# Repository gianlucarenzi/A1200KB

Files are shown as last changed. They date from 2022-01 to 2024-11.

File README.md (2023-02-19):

# A1200KB Amiga 1200 mechanical keyboard

As of right now this is revision 4. I know it could be improved very, very slightly by changing the position of key groups by less than a millimetre but I think it's complete now. 

This PCB design was reverse-engineered from the original keyboard in an Amiga 1200. It is designed to connect to your Amiga 1200 with no modifications to the original machine, just take out the original keyboard and store it away safely. If you want an A600 keyboard, see my other repositories.

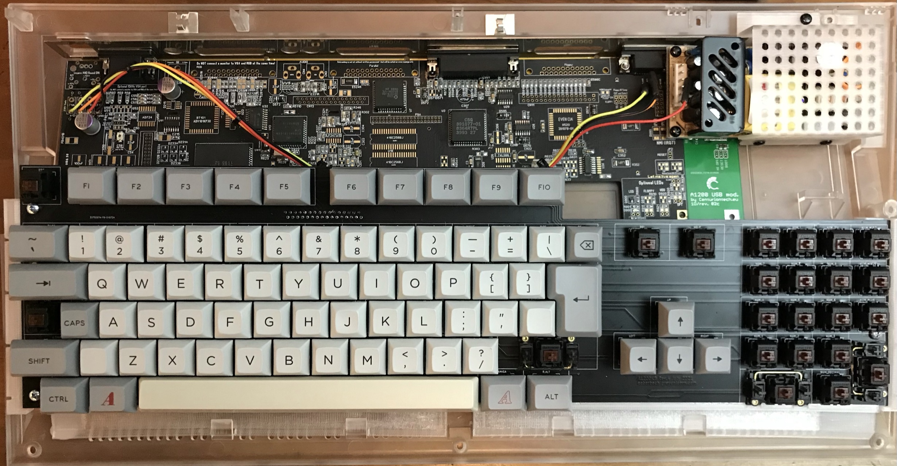
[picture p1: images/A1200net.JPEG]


The A1200.net case (with internal PSU and partially-completed [ReAmiga](http://www.reamiga.info/) board)

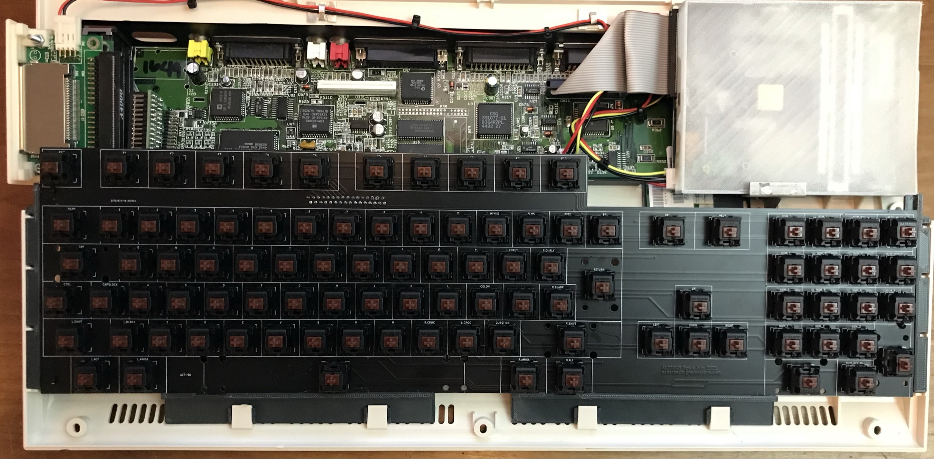
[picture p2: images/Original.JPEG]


The original Amiga case (with CF disk system and transparent floppy cover)

## Requirements
To make a working keyboard for your Amiga 1200, you need:

- one PCB (this project)
- MX-compatible PCB-mount keyswitches, one for each key
- one LED (caps lock)
- one FFC connector, 32-way RA 1.25mm pitch. Molex 52044-3245 is one example, available from Mouser Electronics.
- one FFC ribbon cable, 32-way, 1.25mm pitch. Molex 15168-0400 is one example, available from Mouser Electronics.
- keycaps
- some way to mount the keyboard inside the Amiga (3D print some brackets from the STL folder...)
 
## Design
The Amiga 1200 keyboard is a simple passive key matrix connected via a 31-conductor cable. Some special keys are not on the matrix but have a dedicated circuit, such as the CTRL and Amiga keys - this is why so many conductors are necessary. The original Amiga 1200 PCB uses a 31-way FFC connector, I was not able to buy this anywhere as they are long discontinued. However cutting one conductor away from the cable allows it to fit in the Amiga connector with 31 conductors and to the keyboard with 32 conductors and everything is fine. The specified FFC cable is slightly longer than required but in 2019 there is not  a lot of choice available, so the longer one will do. 
I had my boards made with 1.6mm PCB substrate as any other thickness gets disproportionally expensive, no other special options. Using a piece of aluminium rail, 10x3mm, will make it as stiff as a keyboard should be while maintaining enough space underneath for an accelerator or Indivision etc. This is supported either side by the 3D printed mounts. Cover the aluminium with some kapton or other insulation if you have other internal components that may come dangerously close but in a stock Amiga there is plenty of clearance.

### Amiga Keycaps
These aren't widely available. I've tried making some using a blank set of keycaps from aliexpress and a laser etcher, but I do not know of anywhere that sells a MX-stem set of Amiga keycaps. I am using a 9U space bar but you can just as easily use 7U. If gaps either side of the space bother you, 3D print something to fill the space.

If you want a perfect set of keys, visit pimpmykeyboard.com - it will not be cheap but if you look hard enough you will find every key, even the Amiga keys, and you can have any legend printed on any size keycap so it is possible to make a perfect set. It will not be cheap. You can se a partial sample in the A1200.net picture. I am currently waiting for the extra numpad keys to arrive to complete this keyboard.

## Construction
Without going into all the detail here - as there is lots of detail on www.grayunicorn.com - I rate this a mid-level project. There is no power, no delicate soldering, and nothing can really be inserted the wrong way. Mounting the keyboard requires 3D printing the files you will find in the 3Dfiles folder.

If you have a replacement case produced by A1200.net then pick that folder, else the other folder. I don't know about cases made by ESCOM but I don't think they are at all different from the Commodore cases. I printed these in PETG, 0.4mm nozzle, 0.2mm layer height, supports are necessary. Mounting the keyboard with these designs allows the use of an accelerator card with a thick SIMM; I may design alternates if I get a slimmer accelerator, bringing the keys further back into the case but there is not much room.
 
You can damage your Amiga if you don't know what you are doing. Please be careful and if you are not experienced in projects like this get some help, maybe vist your local makerspace, and don't hurt yourself or your computer.

## Share
Most of all - if you have any suggestions for improvements, adding an issue or a pull request to this repo would be much appreciated. And share your project with the Amiga community, I'd really like to see what you made.

#### Donate?
I hate to think what this has cost so far. It's been fun and I'd do it again, but if you'd like to help the next project happen that would be awesome.



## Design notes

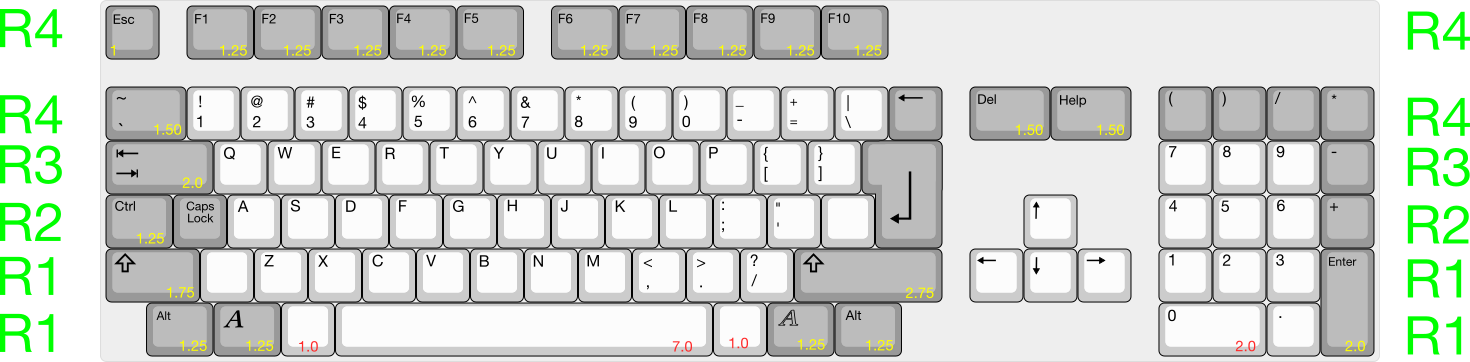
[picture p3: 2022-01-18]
PlatePCB/amiga-keyboard-a500-a1200.png

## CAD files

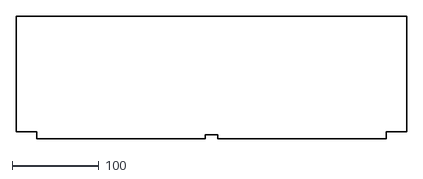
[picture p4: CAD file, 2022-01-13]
created/keyboard_full-Edge_Cuts.dxf
449.3 x 141.4

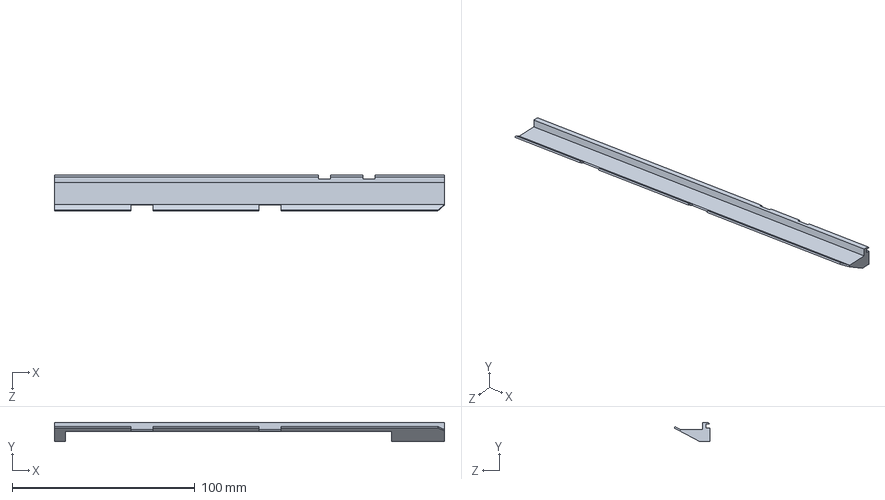
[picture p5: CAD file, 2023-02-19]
3Dfiles/A1200.net case/rev4/Right base.SLDPRT
213.5 x 10.6 x 19.5 mm

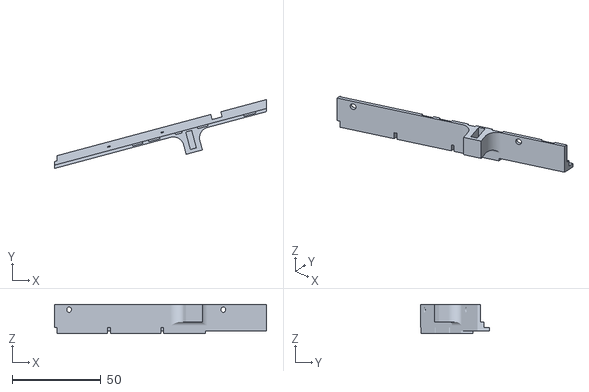
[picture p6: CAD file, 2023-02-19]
3Dfiles/Original Amiga case/rev2+3/Keyboard support left r2.stl
119.5 x 38.9 x 16.5

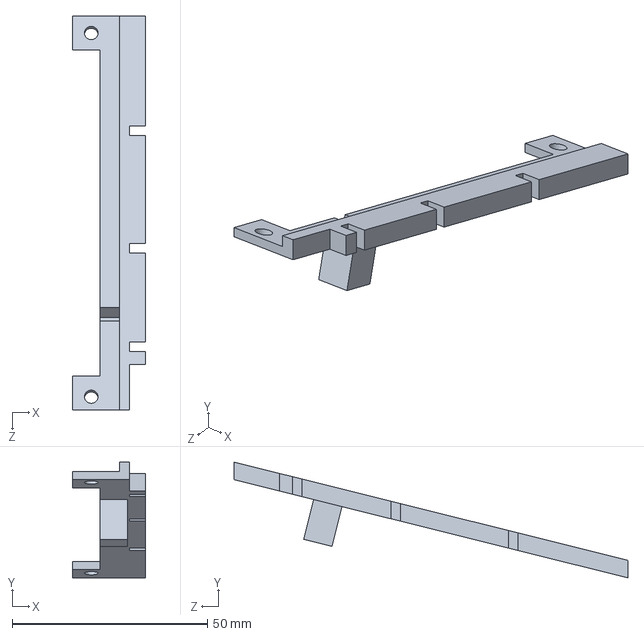
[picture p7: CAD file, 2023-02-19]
3Dfiles/Original Amiga case/rev4/Left side.SLDPRT
18.6 x 29.7 x 100.9 mm

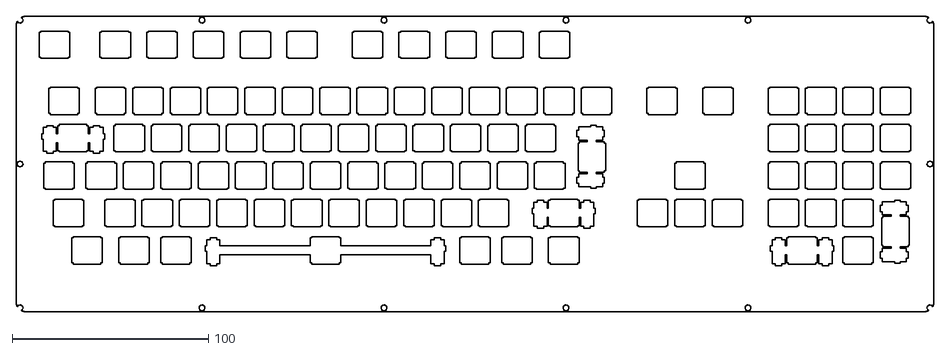
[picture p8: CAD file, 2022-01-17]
PlatePCB/Amiga_Keyboard_Plate_Builder_A1200-A500.dxf
467.7 x 150.6

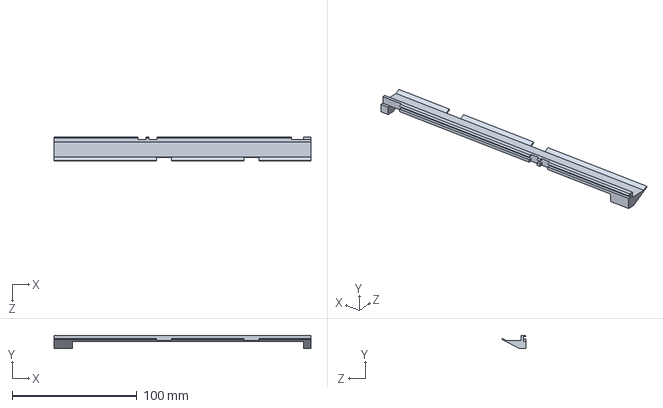
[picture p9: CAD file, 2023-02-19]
3Dfiles/A1200.net case/rev4/Left base.SLDPRT
206.0 x 10.6 x 19.5 mm

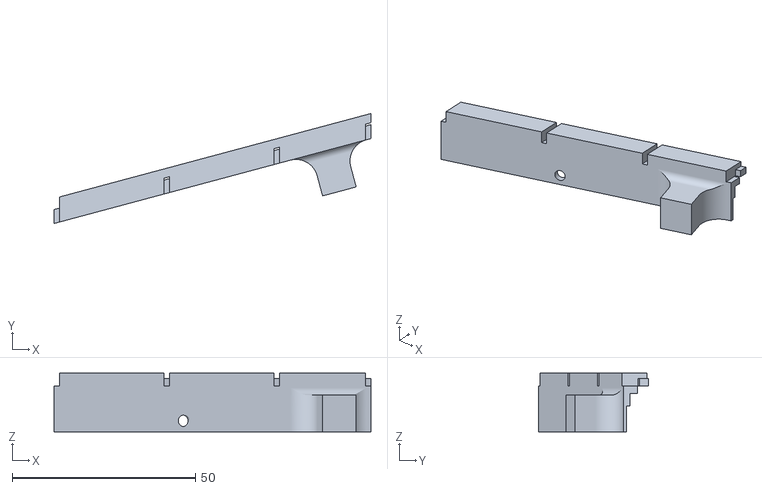
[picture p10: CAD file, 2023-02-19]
3Dfiles/Original Amiga case/rev2+3/Keyboard support right r2.stl
86.5 x 30.0 x 16.0

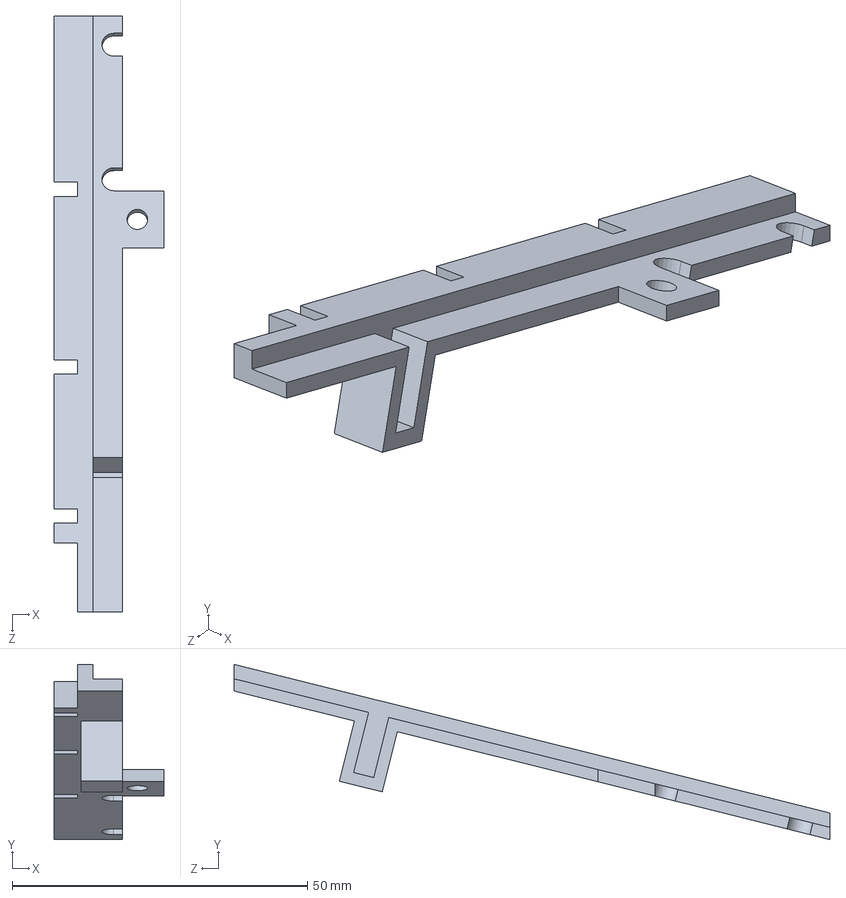
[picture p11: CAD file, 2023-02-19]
3Dfiles/Original Amiga case/rev4/Right side.SLDPRT
18.6 x 29.7 x 100.9 mm

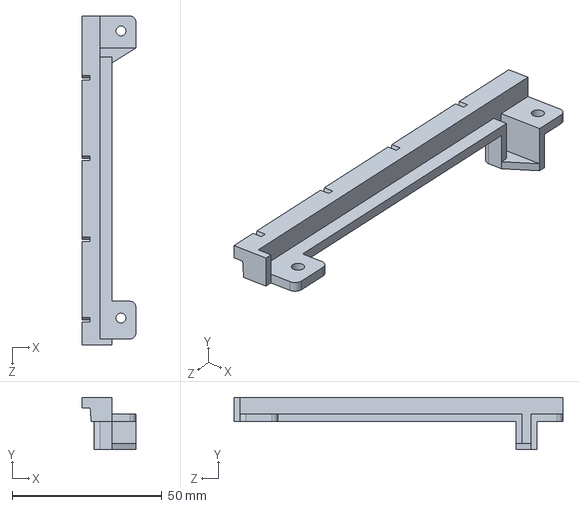
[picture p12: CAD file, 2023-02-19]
3Dfiles/A1200.net case/rev4/Left side.SLDPRT
18.0 x 17.5 x 110.0 mm

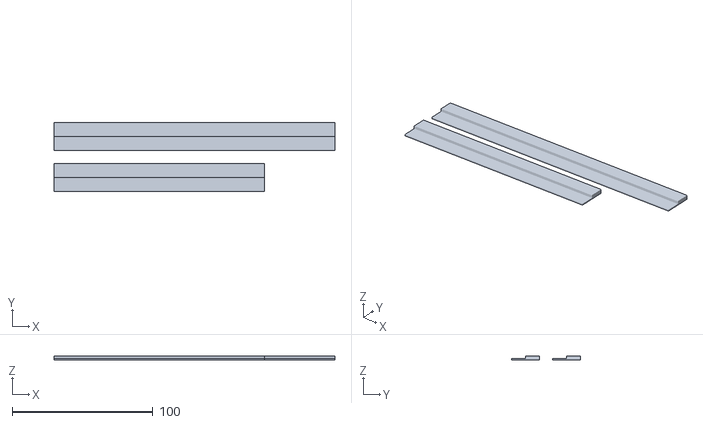
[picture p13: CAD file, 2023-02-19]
3Dfiles/Original Amiga case/rev2+3/kb base.stl
200.0 x 49.0 x 3.00

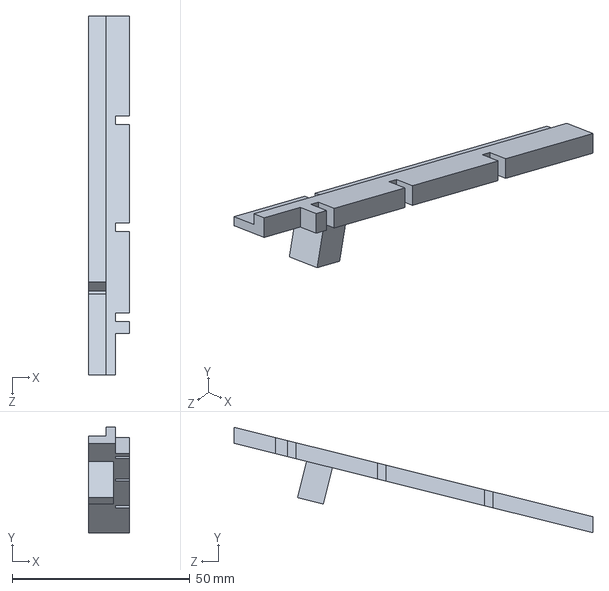
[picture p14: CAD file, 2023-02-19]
3Dfiles/Original Amiga case/rev4/Left side (for mirror).SLDPRT
11.6 x 29.7 x 100.9 mm

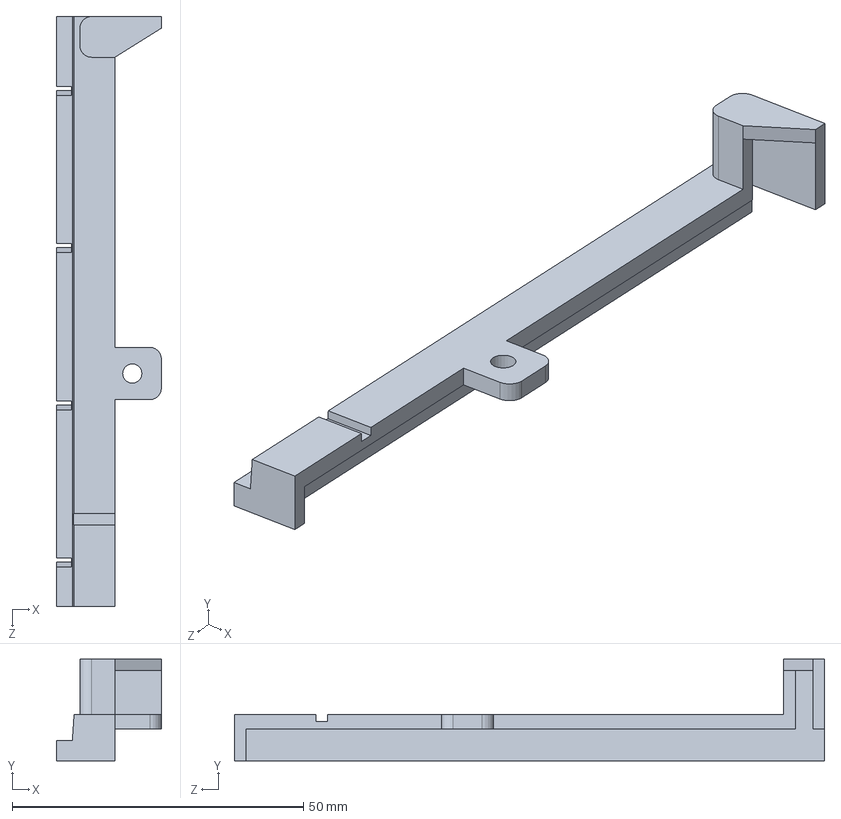
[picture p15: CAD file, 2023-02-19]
3Dfiles/A1200.net case/rev4/Right side.SLDPRT
18.0 x 17.5 x 101.3 mm

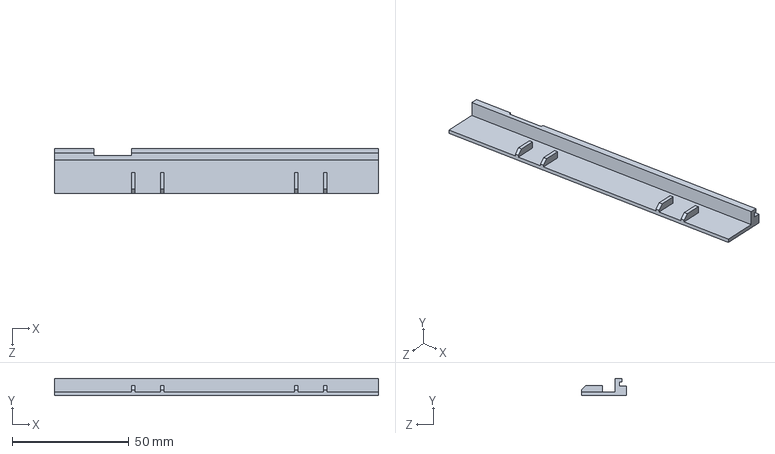
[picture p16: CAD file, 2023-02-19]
3Dfiles/Original Amiga case/rev4/Base.SLDPRT
139.0 x 7.35 x 19.5 mm

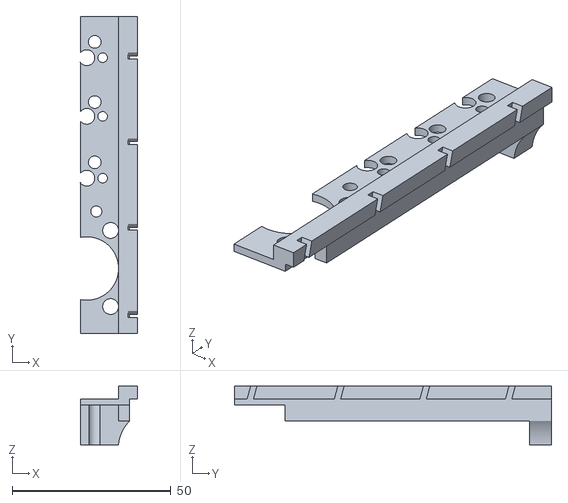
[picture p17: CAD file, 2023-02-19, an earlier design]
3Dfiles/A1200.net case/rev3/Right side.stl
18.0 x 100.0 x 18.5

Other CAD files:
PlatePCB/spacebar-9U-1U-7U-1U.dxf
3Dfiles/A1200.net case/rev3/Right base support.stl
3Dfiles/A1200.net case/rev3/Brace insulator and spacer.stl
3Dfiles/A1200.net case/rev3/Left base support.stl
3Dfiles/A1200.net case/rev3/Left side.stl
3Dfiles/A1200.net case/rev4/Left base.STL
3Dfiles/A1200.net case/rev4/Left side.STL
3Dfiles/A1200.net case/rev4/Right base.STL
3Dfiles/A1200.net case/rev4/Right side.STL
3Dfiles/Original Amiga case/rev4/Base.STL
3Dfiles/Original Amiga case/rev4/Left side.STL
3Dfiles/Original Amiga case/rev4/Right side.STL
created/keyboard_full-B_Mask.dxf
created/keyboard_full-F_Silkscreen.dxf

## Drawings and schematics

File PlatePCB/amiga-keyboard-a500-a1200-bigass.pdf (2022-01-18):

R4

R4

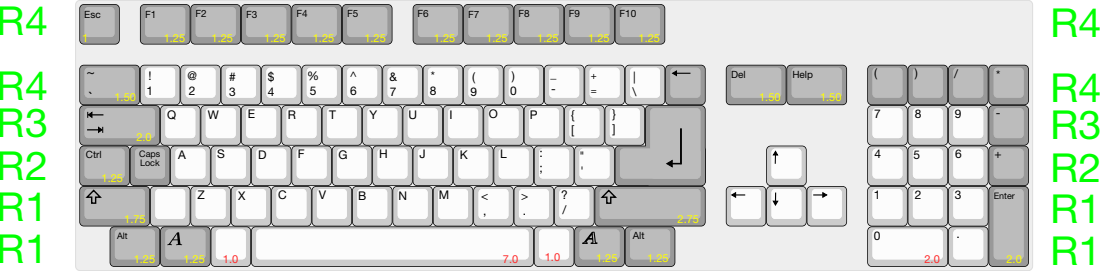
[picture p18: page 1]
Esc; Del; Help `; Caps Lock; Ctrl; Alt; Enter

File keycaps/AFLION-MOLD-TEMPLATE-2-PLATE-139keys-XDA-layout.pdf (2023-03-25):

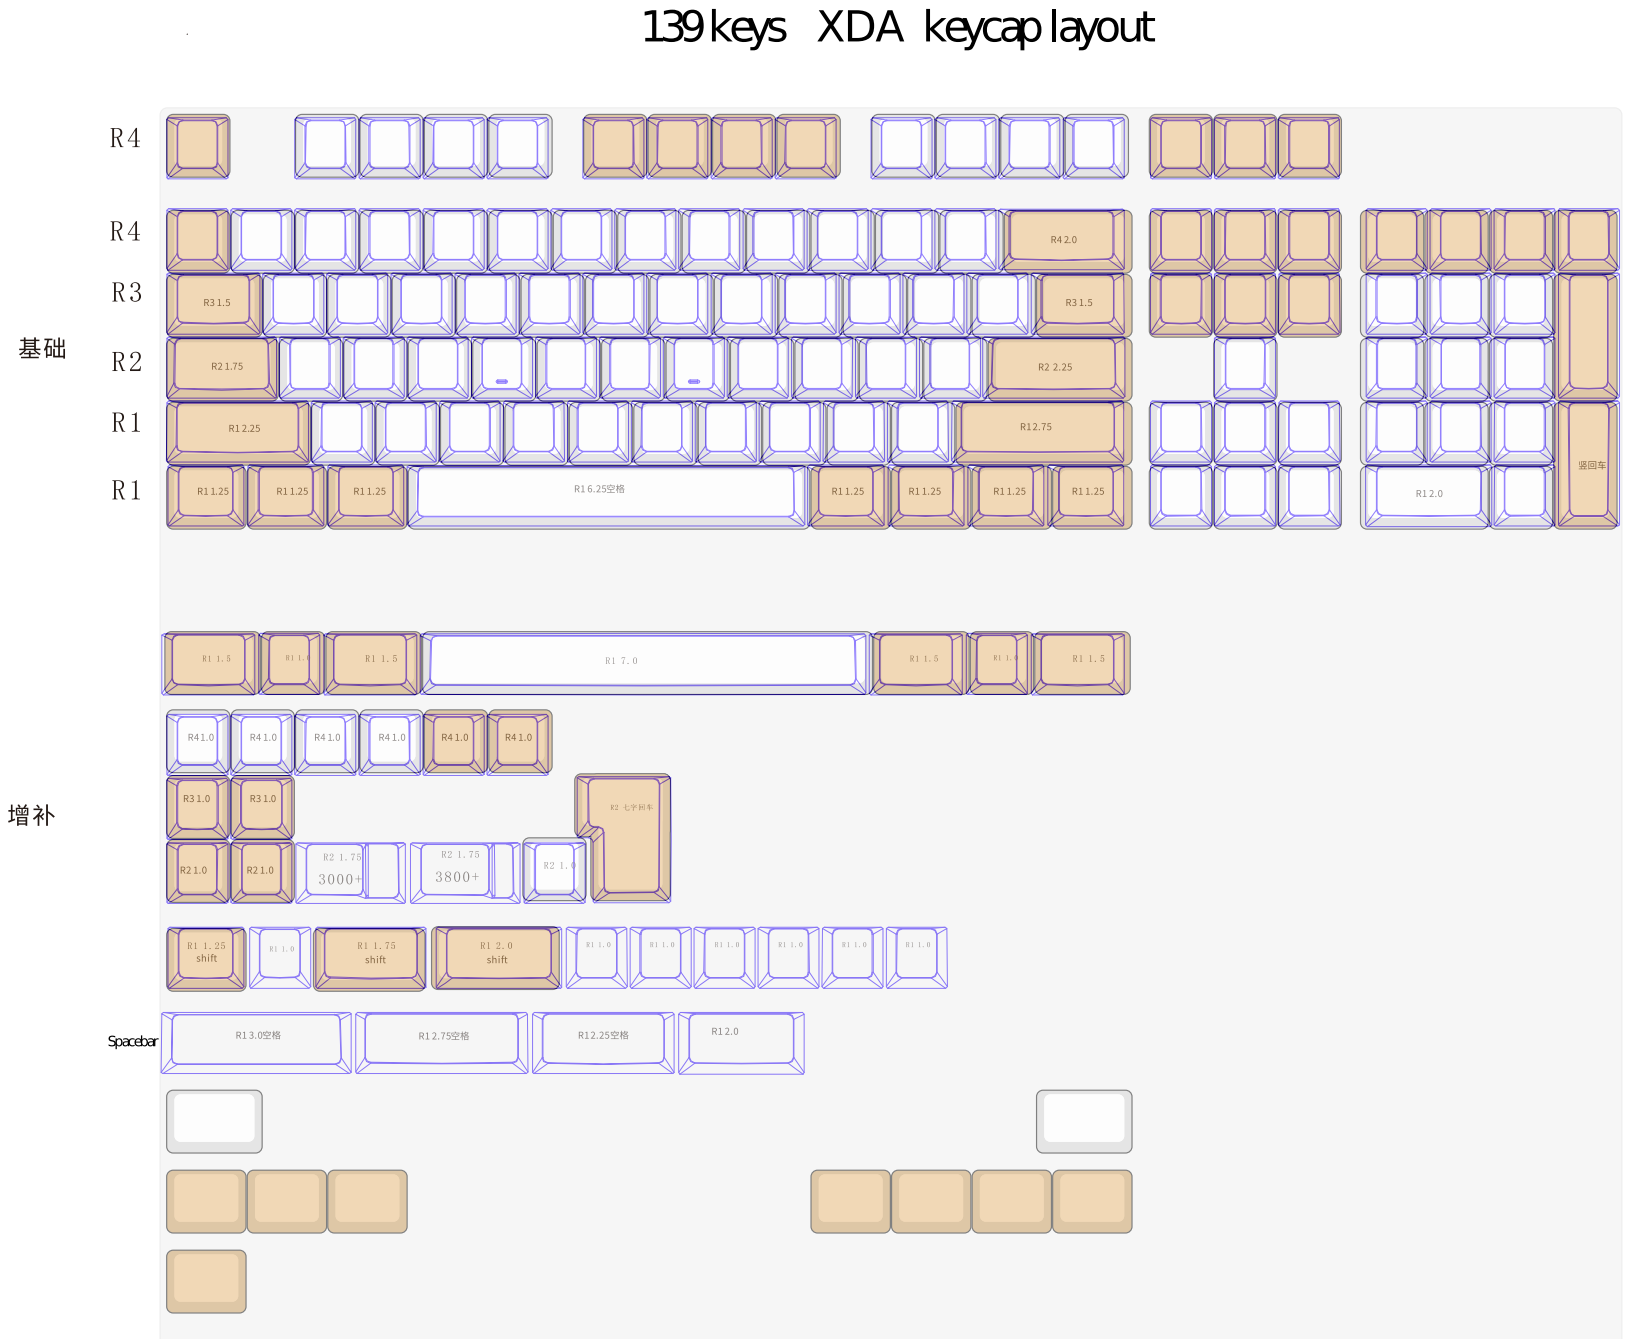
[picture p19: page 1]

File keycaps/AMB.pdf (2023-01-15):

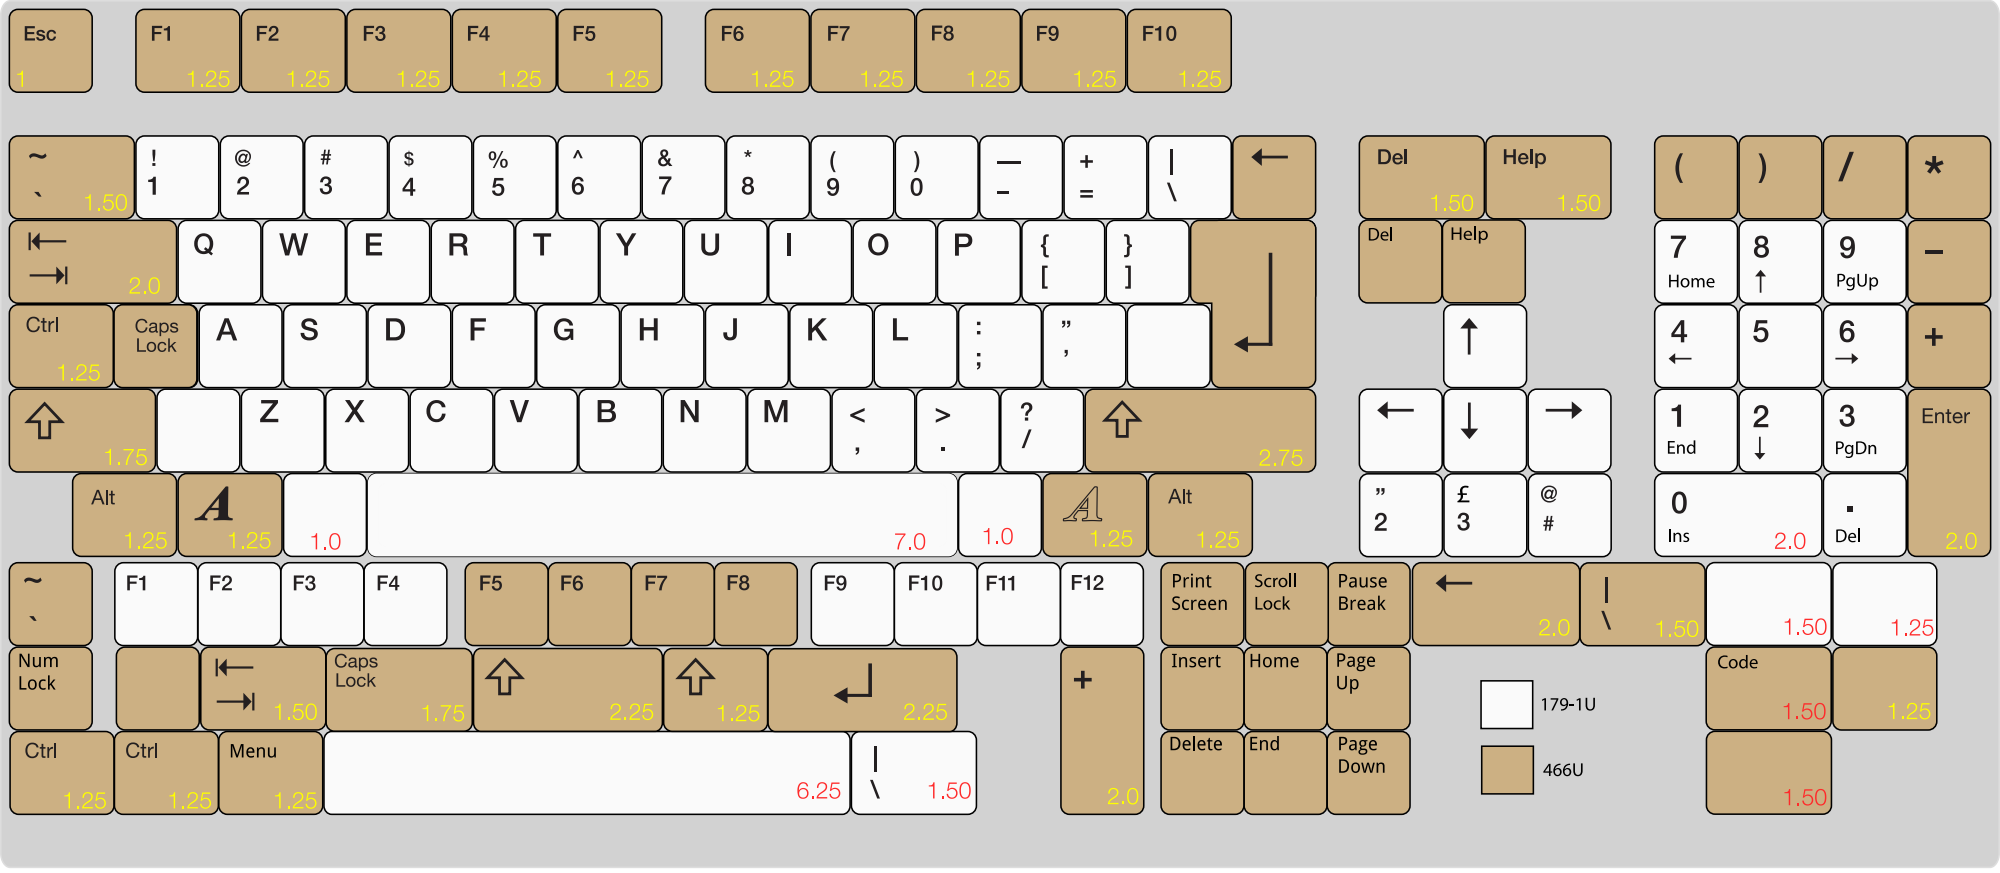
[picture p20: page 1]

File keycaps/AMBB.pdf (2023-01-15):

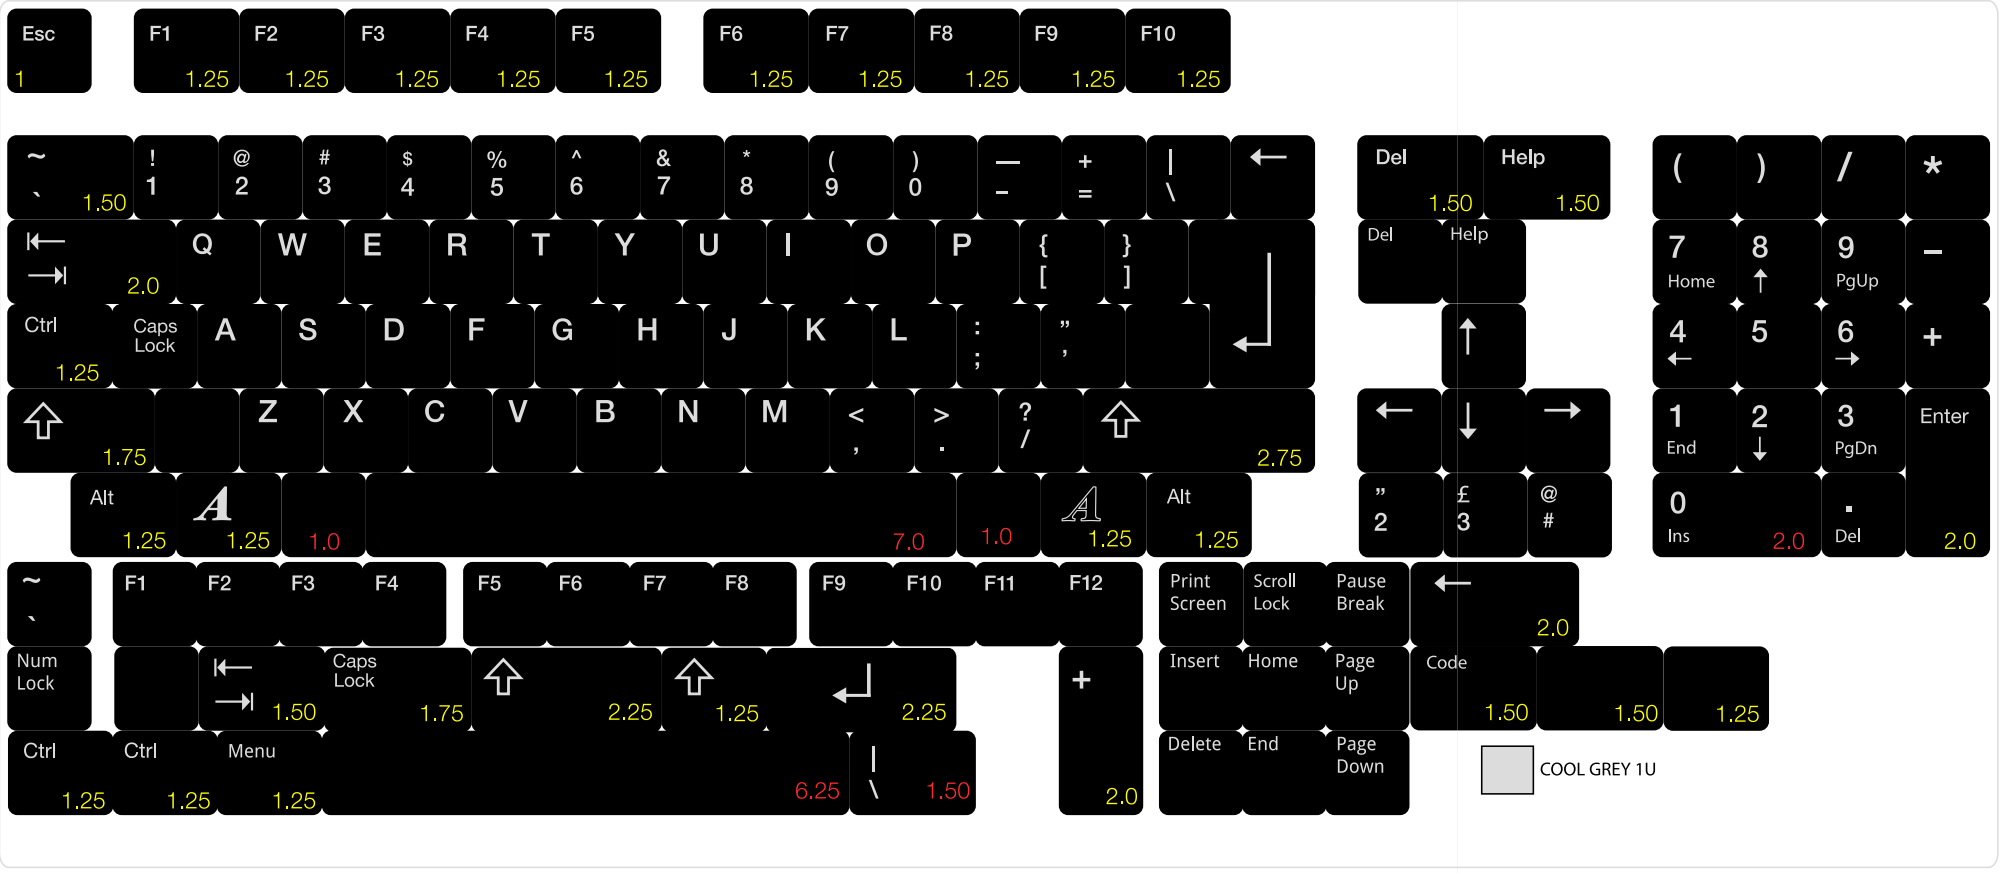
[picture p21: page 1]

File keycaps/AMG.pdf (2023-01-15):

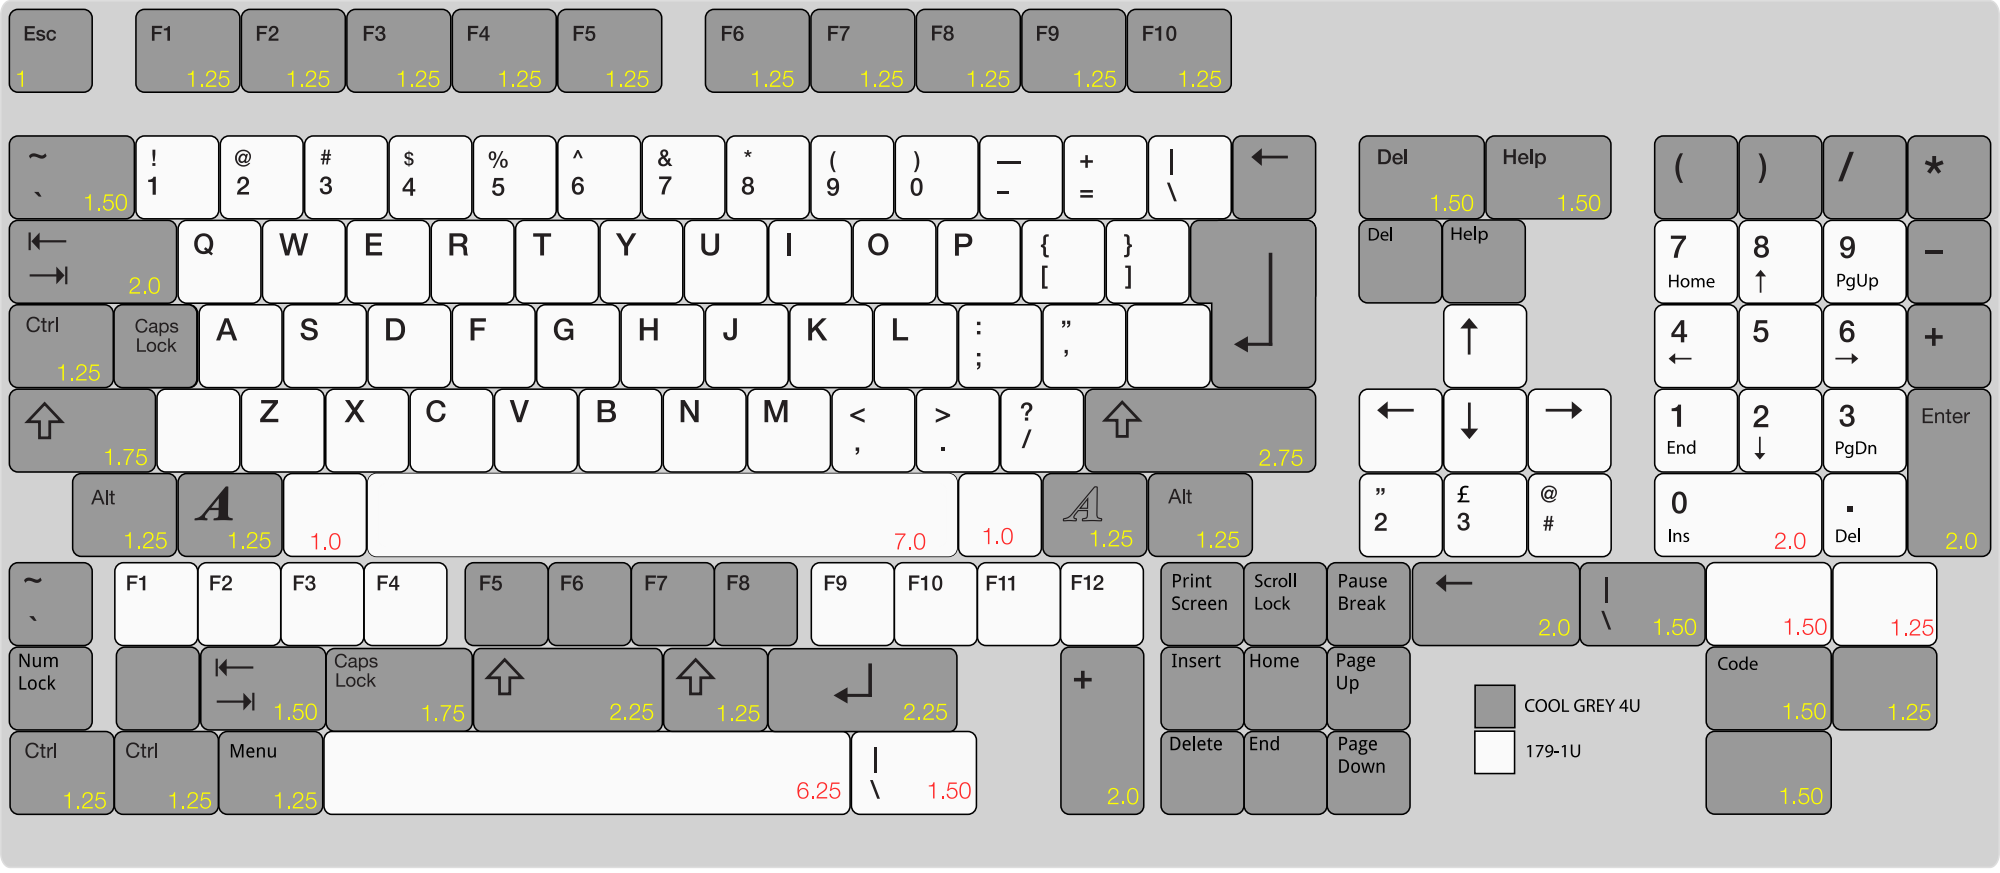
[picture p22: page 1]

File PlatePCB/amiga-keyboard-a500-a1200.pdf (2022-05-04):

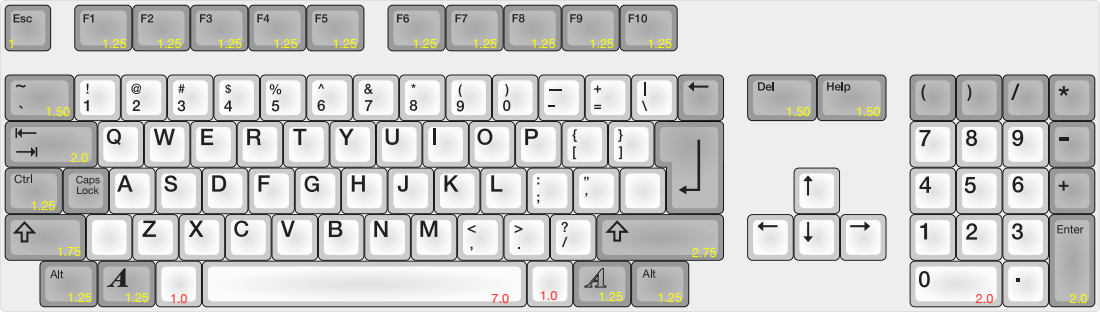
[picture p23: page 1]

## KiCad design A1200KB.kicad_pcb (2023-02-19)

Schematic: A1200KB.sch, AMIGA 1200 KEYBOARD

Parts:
J1: Conn_01x32_Female; FFC-1.25mm-RA-5204403245
K1: ESC; MXOnly-1U-NoLED
K2: F1; MXOnly-1.25U-NoLED
K3: F2; MXOnly-1.25U-NoLED
K4: F3; MXOnly-1.25U-NoLED
K5: F4; MXOnly-1.25U-NoLED
K6: F5; MXOnly-1.25U-NoLED
K7: F6; MXOnly-1.25U-NoLED
K8: F7; MXOnly-1.25U-NoLED
K9: F8; MXOnly-1.25U-NoLED
K10: F9; MXOnly-1.25U-NoLED
K11: F10; MXOnly-1.25U-NoLED
K12: TILDE; MXOnly-1.5U-NoLED
K13: 1; MXOnly-1U-NoLED
K14: 2; MXOnly-1U-NoLED
K15: 3; MXOnly-1U-NoLED
K16: 4; MXOnly-1U-NoLED
K17: 5; MXOnly-1U-NoLED
K18: 6; MXOnly-1U-NoLED
K19: 7; MXOnly-1U-NoLED
K20: 8; MXOnly-1U-NoLED
K21: 9; MXOnly-1U-NoLED
K22: 0; MXOnly-1U-NoLED
K23: MINUS; MXOnly-1U-NoLED
K24: PLUS; MXOnly-1U-NoLED
K25: PIPE; MXOnly-1U-NoLED
K26: BS; MXOnly-1U-NoLED
K27: DEL; MXOnly-1.5U-NoLED
K28: HELP; MXOnly-1.5U-NoLED
K29: NUM_(; MXOnly-1U-NoLED
K30: NUM_); MXOnly-1U-NoLED
K31: NUM_DIV; MXOnly-1U-NoLED
K32: NUM_MULT; MXOnly-1U-NoLED
K33: TAB; MXOnly-2U-NoLED
K34: Q; MXOnly-1U-NoLED
K35: W; MXOnly-1U-NoLED
K36: E; MXOnly-1U-NoLED
K37: R; MXOnly-1U-NoLED
K38: T; MXOnly-1U-NoLED
K39: Y; MXOnly-1U-NoLED
K40: U; MXOnly-1U-NoLED
K41: I; MXOnly-1U-NoLED
K42: O; MXOnly-1U-NoLED
K43: P; MXOnly-1U-NoLED
K44: L.CURLY; MXOnly-1U-NoLED
K45: R.CURLY; MXOnly-1U-NoLED
K46: RETURN; MXOnly-ISO
K47: NUM_7; MXOnly-1U-NoLED
K48: NUM_8; MXOnly-1U-NoLED
K49: NUM_9; MXOnly-1U-NoLED
K50: NUM_MINUS; MXOnly-1U-NoLED
K51: CTRL; MXOnly-1.25U-NoLED
K52: CAPSLOCK; MXOnly-1U
K53: A; MXOnly-1U-NoLED
K54: S; MXOnly-1U-NoLED
K55: D; MXOnly-1U-NoLED
K56: F; MXOnly-1U-NoLED
K57: G; MXOnly-1U-NoLED
K58: H; MXOnly-1U-NoLED
K59: J; MXOnly-1U-NoLED
K60: K; MXOnly-1U-NoLED
K61: L; MXOnly-1U-NoLED
K62: COLON; MXOnly-1U-NoLED
K63: \"; MXOnly-1U-NoLED
K64: R.BLANK; MXOnly-1U-NoLED
K65: UP; MXOnly-1U-NoLED
K66: NUM_4; MXOnly-1U-NoLED
K67: NUM_5; MXOnly-1U-NoLED
K68: NUM_6; MXOnly-1U-NoLED
K69: NUM_PLUS; MXOnly-1U-NoLED
K70: L.SHIFT; MXOnly-1.75U-NoLED
K71: L.BLANK; MXOnly-1U-NoLED
K72: Z; MXOnly-1U-NoLED
K73: X; MXOnly-1U-NoLED
K74: C; MXOnly-1U-NoLED
K75: V; MXOnly-1U-NoLED
K76: B; MXOnly-1U-NoLED
K77: N; MXOnly-1U-NoLED
K78: M; MXOnly-1U-NoLED
K79: R.CROC; MXOnly-1U-NoLED
K80: L.CROC; MXOnly-1U-NoLED
K81: QUESTION; MXOnly-1U-NoLED
K82: R.SHIFT; MXOnly-2.75U-NoLED
K83: LEFT; MXOnly-1U-NoLED
K84: DOWN; MXOnly-1U-NoLED
K85: RIGHT; MXOnly-1U-NoLED
K86: NUM_1; MXOnly-1U-NoLED
K87: NUM_2; MXOnly-1U-NoLED
K88: NUM_3; MXOnly-1U-NoLED
K89: NUM_ENTER; MXOnly-2U-NoLED
K90: L.ALT; MXOnly-1.25U-NoLED
K91: L.AMIGA; MXOnly-1.25U-NoLED
K92: SPACE; MXOnly-7U-NoLED
K93: R.AMIGA; MXOnly-1.25U-NoLED
K94: R.ALT; MXOnly-1.25U-NoLED
K95: NUM_0; MXOnly-2U-NoLED
K96: NUM_DECIMAL; MXOnly-1U-NoLED

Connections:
/1: J1.1, K33.1, K34.2, K35.2, K36.2, K37.2, K38.2, K39.1, K40.2, K41.2, K42.2, K43.2, K44.2, K45.2, K46.1, K83.2
/2: J1.2, K27.2, K52.2, K53.2, K54.2, K55.2, K56.2, K57.2, K58.1, K59.2, K60.2, K61.2, K62.2, K63.2, K64.2, K85.2
/3: J1.3, K26.2, K71.2, K72.2, K73.2, K74.2, K75.2, K76.2, K77.1, K78.2, K79.2, K80.2, K81.2, K84.1, K92.2
/4: J1.4, K32.2, K47.2, K48.2, K49.2, K50.2, K66.2, K67.2, K68.2, K69.2, K86.2, K87.2, K88.2, K89.2, K95.1, K96.2
/5: J1.5, K12.2, K13.2, K14.2, K15.2, K16.2, K17.2, K18.1, K19.2, K20.1, K21.2, K22.2, K23.2, K24.2, K25.1, K65.1
/6: J1.6, K82.1
/7: J1.7, K1.2, K2.2, K3.2, K4.2, K5.2, K6.2, K7.1, K8.2, K9.2, K10.2, K11.2, K28.2, K29.2, K30.2, K31.2
/8: J1.8, K94.1
/9: J1.9, K52.3
/10: J1.10, K93.2
/11: J1.11, K51.2
/12: J1.12, K70.2
/13: J1.13, K90.2
/14: J1.14, K91.2
/15: J1.15, K1.1, K12.1, K32.1, K33.2, K52.1, K71.1
/16: J1.16, K13.1, K29.1, K34.1, K53.1, K69.1, K72.1
/17: J1.17, K2.1, K14.1, K35.1, K49.1, K54.1, K73.1
/18: J1.18, K3.1, K15.1, K36.1, K55.1, K68.1, K74.1
/19: J1.19, K4.1, K16.1, K37.1, K56.1, K75.1, K88.1
/20: J1.20, K5.1, K17.1, K38.1, K57.1, K76.1, K96.1
/21: J1.21, K6.1, K18.2, K39.2, K48.1, K58.2, K77.2
/22: J1.22, K19.1, K30.1, K40.1, K59.1, K67.1, K78.1
/23: J1.23, K7.2, K20.2, K41.1, K60.1, K79.1, K87.1
/24: J1.24, K21.1, K31.1, K42.1, K61.1, K80.1, K89.1
/25: J1.25, K8.1, K22.1, K43.1, K47.1, K62.1, K81.1
/26: J1.26, K9.1, K23.1, K44.1, K63.1, K66.1
/27: J1.27, K10.1, K24.1, K45.1, K64.1, K86.1, K92.1
/28: J1.28, K11.1, K25.2, K26.1, K27.1, K46.2, K95.2
/29: J1.29, K28.1, K50.1, K65.2, K83.1, K84.2, K85.1
/30: J1.30, K51.1, K70.1, K82.2, K90.1, K91.1, K93.1, K94.2
/31: J1.31, K52.4

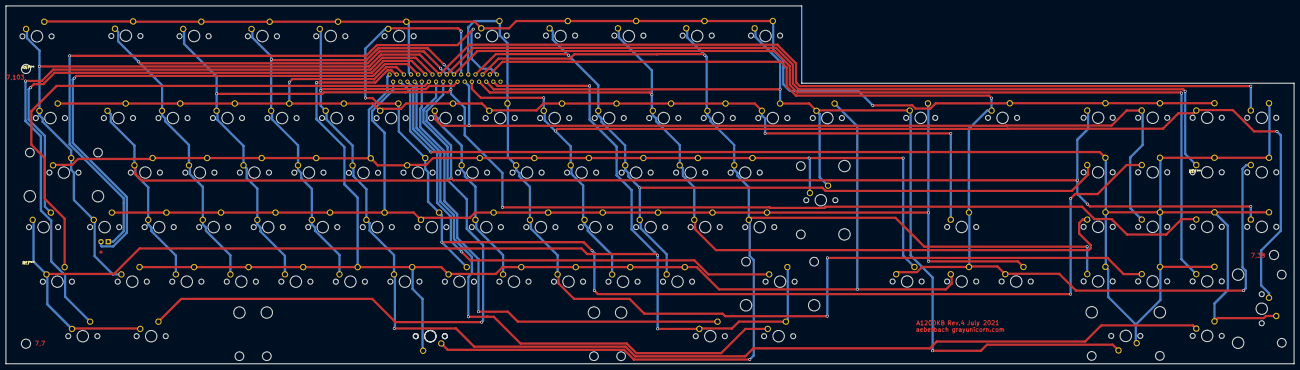
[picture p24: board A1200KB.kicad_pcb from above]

Board: 2 copper layers, 450.0 x 125.0 mm, 97 parts (1 on the bottom side), 31 nets.

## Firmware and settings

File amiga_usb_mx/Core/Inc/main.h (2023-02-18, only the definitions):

#define ROW0_Pin GPIO_PIN_0
#define ROW0_GPIO_Port GPIOB
#define ROW1_Pin GPIO_PIN_1
#define ROW1_GPIO_Port GPIOB
#define ROW2_Pin GPIO_PIN_2
#define ROW2_GPIO_Port GPIOB
#define ROW3_Pin GPIO_PIN_3
#define ROW3_GPIO_Port GPIOB
#define ROW4_Pin GPIO_PIN_4
#define ROW4_GPIO_Port GPIOB
#define ROW5_Pin GPIO_PIN_5
#define ROW5_GPIO_Port GPIOB
#define ROW6_Pin GPIO_PIN_6
#define ROW6_GPIO_Port GPIOB
#define ROW7_Pin GPIO_PIN_7
#define ROW7_GPIO_Port GPIOB
#define ROW8_Pin GPIO_PIN_8
#define ROW8_GPIO_Port GPIOB
#define ROW9_Pin GPIO_PIN_9
#define ROW9_GPIO_Port GPIOB
#define ROW10_Pin GPIO_PIN_10
#define ROW10_GPIO_Port GPIOB
#define ROW11_Pin GPIO_PIN_12
#define ROW11_GPIO_Port GPIOB
#define ROW12_Pin GPIO_PIN_13
#define ROW12_GPIO_Port GPIOB
#define COL0_Pin GPIO_PIN_0
#define COL0_GPIO_Port GPIOC
#define COL1_Pin GPIO_PIN_1
#define COL1_GPIO_Port GPIOC
#define COL2_Pin GPIO_PIN_2
#define COL2_GPIO_Port GPIOC
#define COL3_Pin GPIO_PIN_3
#define COL3_GPIO_Port GPIOC
#define COL4_Pin GPIO_PIN_4
#define COL4_GPIO_Port GPIOC
#define COL5_Pin GPIO_PIN_5
#define COL5_GPIO_Port GPIOC
#define COL6_Pin GPIO_PIN_6
#define COL6_GPIO_Port GPIOC
#define COL7_Pin GPIO_PIN_7
#define COL7_GPIO_Port GPIOC
#define COL8_Pin GPIO_PIN_8
#define COL8_GPIO_Port GPIOC
#define COL9_Pin GPIO_PIN_9
#define COL9_GPIO_Port GPIOC
#define COL10_Pin GPIO_PIN_10
#define COL10_GPIO_Port GPIOC
#define COL11_Pin GPIO_PIN_11
#define COL11_GPIO_Port GPIOC
#define COL12_Pin GPIO_PIN_12
#define COL12_GPIO_Port GPIOC
#define COL13_Pin GPIO_PIN_13
#define COL13_GPIO_Port GPIOC
#define COL14_Pin GPIO_PIN_14
#define COL14_GPIO_Port GPIOC
#define COL15_Pin GPIO_PIN_15
#define COL15_GPIO_Port GPIOC
#define DEBUG_TX_Pin GPIO_PIN_2
#define DEBUG_TX_GPIO_Port GPIOA
#define DEBUG_RX_Pin GPIO_PIN_3
#define DEBUG_RX_GPIO_Port GPIOA
#define KB_DAT_Pin GPIO_PIN_5
#define KB_DAT_GPIO_Port GPIOA
#define KB_CLK_Pin GPIO_PIN_6
#define KB_CLK_GPIO_Port GPIOA
#define KB_RST_Pin GPIO_PIN_7
#define KB_RST_GPIO_Port GPIOA
#define KB_AMIGA_GPIO_Port GPIOA
#define LED_CAPS_LOCK_Pin GPIO_PIN_8
#define LED_CAPS_LOCK_GPIO_Port GPIOA
#define LED_NUM_LOCK_Pin GPIO_PIN_9
#define LED_NUM_LOCK_GPIO_Port GPIOA
#define LED_SCROLL_LOCK_Pin GPIO_PIN_10
#define LED_SCROLL_LOCK_GPIO_Port GPIOA
#define LED_ACT_Pin GPIO_PIN_0
#define LED_ACT_GPIO_Port GPIOA
#define LEDS_GPIO_Port GPIOA

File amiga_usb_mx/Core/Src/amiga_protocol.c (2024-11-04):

/**
 * Amiga housekeeping as MPU.
 * Written by Gianluca Renzi R.G.
 * License for this code: LGPLv3
 * Please refer to this license at GNU Web Site
 * https://www.gnu.org/licenses/lgpl-3.0.html
 * 
 **/
#include <string.h>
#include <stdlib.h>
#include <stdbool.h>
#include "syscall.h"
#include "keyboard.h"
#include "keycode.h"
#include "config.h"
#include "amiga_config.h"
#include "debug.h"
#include "amiga_protocol.h"
#include "debug.h"
#include "main.h" // For GPIO pins definition
#include "hook.h"

static int debuglevel = DBG_INFO;

#define KEY_NONE                               0x00
#define KEY_ERRORROLLOVER                      0x01
#define KEY_POSTFAIL                           0x02
#define KEY_ERRORUNDEFINED                     0x03
#define KEY_A                                  0x04
#define KEY_B                                  0x05
#define KEY_C                                  0x06
#define KEY_D                                  0x07
#define KEY_E                                  0x08
#define KEY_F                                  0x09
#define KEY_G                                  0x0A
#define KEY_H                                  0x0B
#define KEY_I                                  0x0C
#define KEY_J                                  0x0D
#define KEY_K                                  0x0E
#define KEY_L                                  0x0F
#define KEY_M                                  0x10
#define KEY_N                                  0x11
#define KEY_O                                  0x12
#define KEY_P                                  0x13
#define KEY_Q                                  0x14
#define KEY_R                                  0x15
#define KEY_S                                  0x16
#define KEY_T                                  0x17
#define KEY_U                                  0x18
#define KEY_V                                  0x19
#define KEY_W                                  0x1A
#define KEY_X                                  0x1B
#define KEY_Y                                  0x1C
#define KEY_Z                                  0x1D
#define KEY_1_EXCLAMATION_MARK                 0x1E
#define KEY_2_AT                               0x1F
#define KEY_3_NUMBER_SIGN                      0x20
#define KEY_4_DOLLAR                           0x21
#define KEY_5_PERCENT                          0x22
#define KEY_6_CARET                            0x23
#define KEY_7_AMPERSAND                        0x24
#define KEY_8_ASTERISK                         0x25
#define KEY_9_OPARENTHESIS                     0x26
#define KEY_0_CPARENTHESIS                     0x27
#define KEY_ENTER                              0x28
#define KEY_ESCAPE                             0x29
#define KEY_BACKSPACE                          0x2A
#define KEY_TAB                                0x2B
#define KEY_SPACEBAR                           0x2C
#define KEY_MINUS_UNDERSCORE                   0x2D
#define KEY_EQUAL_PLUS                         0x2E
#define KEY_OBRACKET_AND_OBRACE                0x2F
#define KEY_CBRACKET_AND_CBRACE                0x30
#define KEY_BACKSLASH_VERTICAL_BAR             0x31
#define KEY_NONUS_NUMBER_SIGN_TILDE            0x32
#define KEY_SEMICOLON_COLON                    0x33
#define KEY_SINGLE_AND_DOUBLE_QUOTE            0x34
#define KEY_GRAVE_ACCENT_AND_TILDE             0x35
#define KEY_COMMA_AND_LESS                     0x36
#define KEY_DOT_GREATER                        0x37
#define KEY_SLASH_QUESTION                     0x38
#define KEY_CAPS_LOCK                          0x39
#define KEY_F1                                 0x3A
#define KEY_F2                                 0x3B
#define KEY_F3                                 0x3C
#define KEY_F4                                 0x3D
#define KEY_F5                                 0x3E
#define KEY_F6                                 0x3F
#define KEY_F7                                 0x40
#define KEY_F8                                 0x41
#define KEY_F9                                 0x42
#define KEY_F10                                0x43
#define KEY_F11                                0x44
#define KEY_F12                                0x45
#define KEY_PRINTSCREEN                        0x46
#define KEY_SCROLL_LOCK                        0x47
#define KEY_PAUSE                              0x48
#define KEY_INSERT                             0x49
#define KEY_HOME                               0x4A
#define KEY_PAGEUP                             0x4B
#define KEY_DELETE                             0x4C
#define KEY_END1                               0x4D
#define KEY_PAGEDOWN                           0x4E
#define KEY_RIGHTARROW                         0x4F
#define KEY_LEFTARROW                          0x50
#define KEY_DOWNARROW                          0x51
#define KEY_UPARROW                            0x52
#define KEY_KEYPAD_NUM_LOCK_AND_CLEAR          0x53
#define KEY_KEYPAD_SLASH                       0x54
#define KEY_KEYPAD_ASTERIKS                    0x55
#define KEY_KEYPAD_MINUS                       0x56
#define KEY_KEYPAD_PLUS                        0x57
#define KEY_KEYPAD_ENTER                       0x58
#define KEY_KEYPAD_1_END                       0x59
#define KEY_KEYPAD_2_DOWN_ARROW                0x5A
#define KEY_KEYPAD_3_PAGEDN                    0x5B
#define KEY_KEYPAD_4_LEFT_ARROW                0x5C
#define KEY_KEYPAD_5                           0x5D
#define KEY_KEYPAD_6_RIGHT_ARROW               0x5E
#define KEY_KEYPAD_7_HOME                      0x5F
#define KEY_KEYPAD_8_UP_ARROW                  0x60
#define KEY_KEYPAD_9_PAGEUP                    0x61
#define KEY_KEYPAD_0_INSERT                    0x62
#define KEY_KEYPAD_DECIMAL_SEPARATOR_DELETE    0x63
#define KEY_NONUS_BACK_SLASH_VERTICAL_BAR      0x64
#define KEY_APPLICATION                        0x65
#define KEY_POWER                              0x66
#define KEY_KEYPAD_EQUAL                       0x67
#define KEY_F13                                0x68
#define KEY_F14                                0x69
#define KEY_F15                                0x6A
#define KEY_F16                                0x6B
#define KEY_F17                                0x6C
#define KEY_F18                                0x6D
#define KEY_F19                                0x6E
#define KEY_F20                                0x6F
#define KEY_F21                                0x70
#define KEY_F22                                0x71
#define KEY_F23                                0x72
#define KEY_F24                                0x73
#define KEY_EXECUTE                            0x74
#define KEY_HELP                               0x75
#define KEY_MENU                               0x76
#define KEY_SELECT                             0x77
#define KEY_STOP                               0x78
#define KEY_AGAIN                              0x79
#define KEY_UNDO                               0x7A
#define KEY_CUT                                0x7B
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

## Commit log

2020-11-22 First Attempt to use online tools for holes and PCB keyset placement.
    [Amiga_Keyboard_Plate_Builder_A1200-A500.dxf]
2022-01-12 New spacebar layout. 7u + 1u + 1u
    [spacebar-9U-1U-7U-1U.dxf]
2022-01-13 Imported from Altium
    [keyboard_full-Edge_Cuts.dxf, keyboard_full-F_Silkscreen.dxf, keyboard_full-User_4.dxf]
2022-01-13 Now has the AmigaComponents.lib dependancy
    [A1200KB.kicad_pcb, A1200KB.sch]
2022-01-14 The ISO Enter here, must have rotated Cherry MX switch by 180 degrees
    [A1200KB.sch]
2022-01-15 Added MCU controller sheet page
    [MCU_Controller.sch]
2022-01-17 Added the autogenerated plate by http://builder.swillkb.com/
    [A1200KB.kicad_pcb]
2022-01-17 This should be used to align on the custom keyboard case. It works even for building a plate for original Amiga case. The plate should be laser cutted and folded to match the original plastic case ho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
    [Amiga_Keyboard_Plate_Builder_A1200-A500.dxf]
2022-01-20 First import from ATARI KEYBOARD CONTROLLER
    [stm32f4eval.cfg]
2022-01-22 Custom 8 timers added. Must be checked on real hardware
2022-01-22 LED_POWER Added (PA4)
2022-01-22 Added POWER LED
2022-06-12 Printed 4 keycaps (31 USD each + shipping 8 USD each + import tax 30%) Changsha Kuangkuang Technology Co., Ltd.
2022-07-06 Removed STM32F401_DK from Page #1. It will be included in the page #2 MCU
2022-07-06 Added some global netlist
    [A1200KB.sch]
2023-01-15 Mechanical MOLD for three prints (AFLION)
2023-02-16 Added the correct molds for XDA profile (139 keys) :-(
2023-02-18 LED on PA0 (GND Active)
2023-02-18 Commodore Braunschweig Amiga VID & PID based on Zorro IDs ;-)
2023-02-19 Updated from AEBERBACH GitHub repo
    [Base.SLDPRT, Base.STL, Brace insulator and spacer.stl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]
2023-03-25 Update to 6.8.0 STM32CubeMX
2024-11-04 Updated with the correct keystroke couple
    [amiga_protocol.c]

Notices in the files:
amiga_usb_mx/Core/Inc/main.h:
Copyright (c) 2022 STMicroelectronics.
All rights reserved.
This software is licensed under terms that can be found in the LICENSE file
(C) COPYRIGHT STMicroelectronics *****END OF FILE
